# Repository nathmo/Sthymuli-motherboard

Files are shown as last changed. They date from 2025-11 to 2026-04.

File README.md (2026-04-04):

# Sthymuli-motherboard
This repo contains the PCB for the Sthymuli motherboard. Sthymuli is an educative robot aimed at children whith the aim of promoting collaborative learning.

The motherboard is designed arround a doughnut shape with addons that plug in the center. the shape was chosen to encourage equal access to up to four children at a time interracting with the device.

the circuit is splitted between one motherboard and three cardinalboard 
this repo has the motherboard


the cardinal board can be found there : https://github.com/nathmo/Sthymuli-cardinalboard


# Feature
The device contains the following sensors 

===

* # USB-C connector
* # Batterie + BMS
* # ESP32 + STM32
* # Speaker
* # Microphone
* # capacitive buttons (distributed arround the doughnut as discussed last time)
* # IR remote receive
* # 4 IR proximity Sensor
* # Motor Driver (so they can just connect the two wire of the motor and dont need to add a Hbridge on the dauther board
* # RGB LED (there I need to count how many and decide with you what we keep and what we breakout for the daugther board

# Daugther boards

the following will be available for the daugther board :

* IMU
* color sensor
* 2 DC motor channel
* LEDs
* IR proximity sensor / analog pin that can be used for sensing

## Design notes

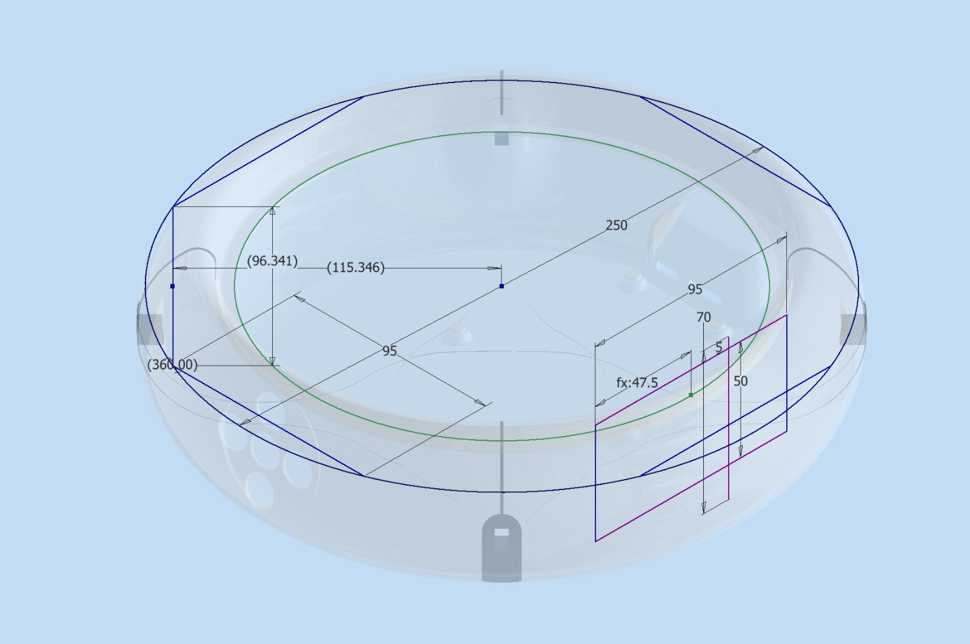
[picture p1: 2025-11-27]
enclosure_sktech_concept.jpg

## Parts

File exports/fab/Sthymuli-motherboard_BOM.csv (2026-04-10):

Comment | Designator | Footprint | JLCPCB Part #
CL05B104KO5NNNC | C1, C2, C3, C4, C5, C6, C7, C32, C45, C54, C58, C65, C67, C78, C86, C89, C94, C96 | C_0402_1005Metric | C1525
CL05B224KO5NNNC | C26, C27, C28, C29, C98 | C_0402_1005Metric | C16772
CL21B105KBFNNNE | C30, C34, C35, C69, C70, C79, C81, C83, C90, C91, C92, C93 | C_0805_2012Metric | C28323
0402CG101J500NT | C31, C33, C61, C62, C63, C66 | C_0402_1005Metric | C1546
CL21A106KAYNNNE | C36, C37, C38, C41, C49, C50, C51, C53, C56, C57, C84, C88, C95 | C_0805_2012Metric | C15850
0402B222K500NT | C39 | C_0402_1005Metric | C1531
CL05A474KP5NNNC | C40 | C_0402_1005Metric | C47339
0402CG330J500NT | C42 | C_0402_1005Metric | C1562
0402CG150J500NT | C43 | C_0402_1005Metric | C1548
0805B681K500NT | C44 | C_0805_2012Metric | C1754
0805B333K500NT | C46, C47 | C_0805_2012Metric | C1739
CL05B103KB5NNNC | C48, C72, C76 | C_0402_1005Metric | C15195
0402B473K500NT | C52, C55 | C_0402_1005Metric | C82219
CL21A226MAQNNNE | C59, C60, C68, C71 | C_0805_2012Metric | C45783
CL21A225KBQNNNE | C64 | C_0805_2012Metric | C377773
0805B152K500NT | C73 | C_0805_2012Metric | C1717
CL05C331JB5NNNC | C74 | C_0402_1005Metric | C13533
CL21A475KAQNNNE | C75 | C_0805_2012Metric | C1779
0402B102K500NT | C80, C82 | C_0402_1005Metric | C1523
0402CG200J500NT | C85, C87 | C_0402_1005Metric | C1554
CL21A226MAQNNNE | C97 | C_0805_2012Metric | C45783
WS2812B-V5/W | D1, D2, D3, D4, D5, D6, D7 | LED_WS2812B_PLCC4_5.0x5.0mm_P3.2mm | C2874885
SM4007PL | D30, D31, D34 | D_SOD-123F | C64898
LESD5D5.0CT1G | D32, D33 | D_SOD-523 | C5246195
ES8374 | ES1 | QFN-28-1EP_4x4mm_P0.45mm_EP2.4x2.4mm | C365738
AO3401A | Q10 | SOT-23 | C15127
HYCW498-USBC16-735B | J1 | USB_C_Receptacle_G-Switch_GT-USB-7010ASV | C42400252
FHD4020S-2R2MT | L1 | FHD4020S-2R2MT | C602029
FXL0630-3R3-M | L2, L3 | FXL0630-3R3-M | C167219
TDK VFS5045VA301 | L4 | TDK VFS5045VA301 | C6913904
KLJ-01304T-08R07W | LS1 | Speaker KELIKING KLJ-01304T-08R07W | C18186315
MIC-4013-G-G00 | MKTD4015BPN1 | SAMZO MIC-4013-G-G00 | C42371093
CSD17551Q3A | Q1, Q2, Q3, Q4, Q5, Q6 | VSON-8_3.3x3.3mm_P0.65mm_NexFET | C2876535
CSD25402Q3A | Q7 | VSON-8_3.3x3.3mm_P0.65mm_NexFET | C111356
NX7002AKVL | Q8, Q9 | SOT-23 | C551606
0603WAF100JT5E | R1, R2, R3, R4, R6, R9, R15, R36, R37 | C_0201_0603Metric | C22859
0603WAF5101T5E | R5, R7 | C_0201_0603Metric | C23186
0603WAF1000T5E | R8, R13, R16, R48, R59, R69, R70 | C_0201_0603Metric | C22775
FRM121WFR001TM | R14 | R_1206_3216Metric | C7467246
0603WAF1003T5E | R17 | C_0201_0603Metric | C25803
0603WAF3003T5E | R18 | C_0201_0603Metric | C23024
0603WAF1005T5E | R19, R26 | C_0201_0603Metric | C7250
0603WAF4703T5E | R20 | C_0201_0603Metric | C23178
0603WAF3003T5E | R21 | C_0201_0603Metric | C23024
0603WAF2201T5E | R22, R23, R49, R58 | C_0201_0603Metric | C4190
0603WAF5101T5E | R24, R28 | C_0201_0603Metric | C23186
0603WAF4022T5E | R25 | C_0201_0603Metric | C12447
0603WAF100KT5E | R27 | C_0201_0603Metric | C22936
0603WAF499KT5E | R29, R31 | C_0201_0603Metric | C23165
0603WAJ010LT5E | R30, R43 | C_0201_0603Metric | C620909
0603WAF1002T5E | R32, R33, R34, R42, R45, R46, R47, R71 | C_0201_0603Metric | C25804
0603WAF3002T5E | R35 | C_0201_0603Metric | C22984
0603WAF4702T5E | R38 | C_0201_0603Metric | C25819
0603WAF1502T5E | R39 | C_0201_0603Metric | C22809
0603WAF1373T5E | R40 | C_0201_0603Metric | C22872
0603WAF5362T5E | R41 | C_0201_0603Metric | C23074
0603WAF1001T5E | R44 | C_0201_0603Metric | C21190
0603WAF3301T5E | R50, R51 | C_0201_0603Metric | C22978
0603WAF270JT5E | R60, R61 | C_0201_0603Metric | C25190
XKB5858-W-F | SW1, SW2, SW3, SW4 | XKB5858 | C2884737
NCP18XH103F03RB | TH1 | R_0603_1608Metric | C13564
ESP32-S3-WROOM-1-N16 | U1 | ESP32-S3-WROOM-1 | C2913199
TPAP2112K-3.3TRG1 | U2 | SOT-23-5 | C3021085
BQ76905RGRR | U3 | IC_BQ76905RGRR | C22394458
AP62300WU-7 | U4, U6 | TSOT-23-6 | C1880390
BQ25713RSNR | U5 | QFN-32-1EP_4x4mm_P0.4mm_EP2.9x2.9mm | BQ25713RSNR
MCP23017-E/SO | U7 | SOIC-28W_7.5x17.9mm_P1.27mm | C47023
AP22913CN4 | U8 | WLCSP-4_0.89x0.89mm_Layout2x2_P0.5mm | C2150198
IRM-H638T/TR2 | U9 | Everlight_IRM-H6xxT | C91447
74HC4051D,653 | U10, U12 | SOIC-16_3.9x9.9mm_P1.27mm | C9386
MCP6L01T-E/OT | U11 | SOT-23-5 | C145745
LSM6DS3TR-C | U14 | LGA-14_3x2.5mm_P0.5mm_LayoutBorder3x4y | C967633
ITR9909 | U15 | ITR_9909_Horizontal | C53399
ITR9909 | U16 | ITR_9909_Vertical | C53399
Battery_Cell | BT4 | Battery_Holder_18650_robop | C7525438
Conn_02x08_Counter_Clockwise | J8, J11, J12 | PinSocket_2x08_P2.54mm_Vertical_SMD | C41427537

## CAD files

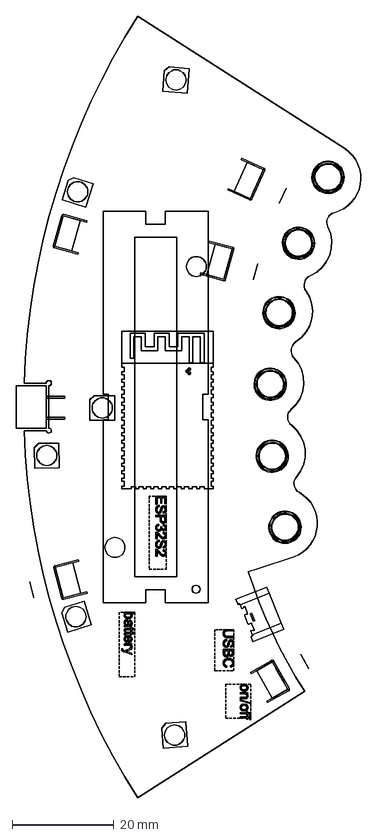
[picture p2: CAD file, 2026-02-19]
DXF_B_MainPCB.dxf
68.1 x 153.6 mm

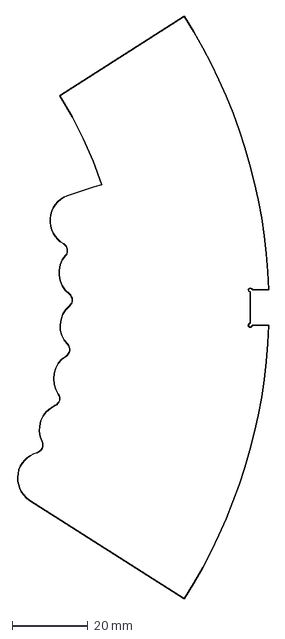
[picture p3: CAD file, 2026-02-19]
DXF_A_MainPCB.dxf
66.6 x 153.6 mm

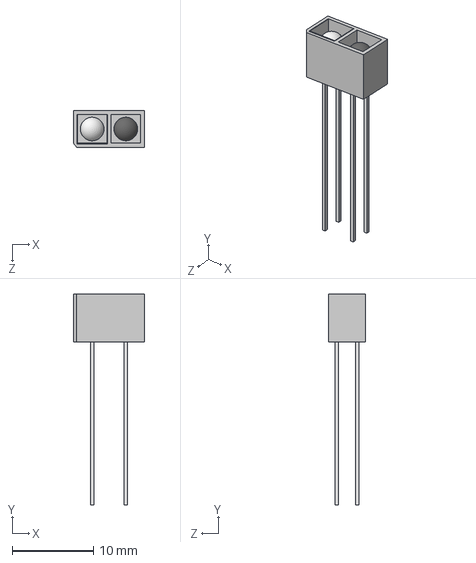
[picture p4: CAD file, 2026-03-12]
footprint/ITR-9909.stp
8.70 x 25.9 x 4.50 mm

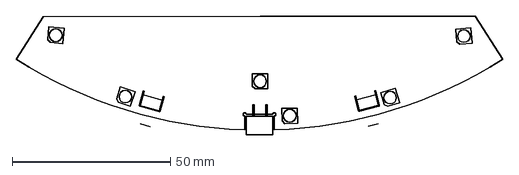
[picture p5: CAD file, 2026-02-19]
DXF_B_MinionPCB.dxf
153.6 x 37.4 mm

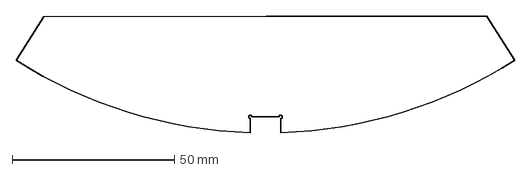
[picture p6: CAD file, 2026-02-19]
DXF_A_MinionPCB.dxf
153.6 x 35.9 mm

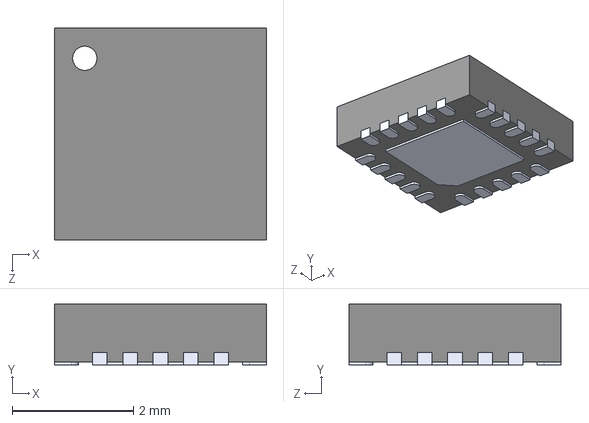
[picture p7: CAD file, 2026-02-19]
footprint/BQ76905RGRR.step
3.50 x 1.00 x 3.50 mm

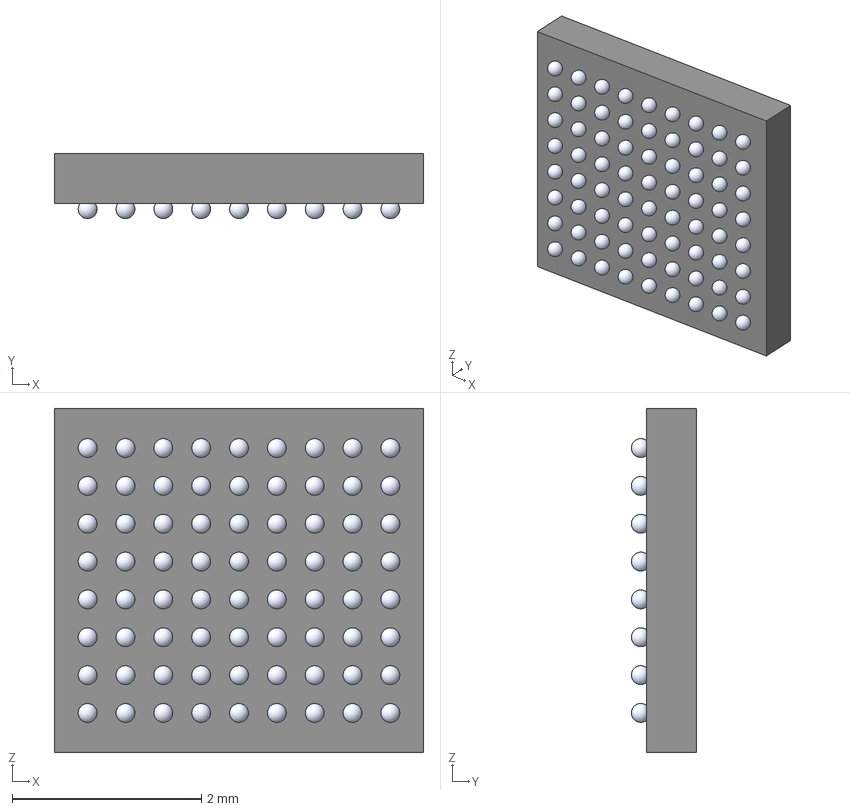
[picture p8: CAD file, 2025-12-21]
footprint/MAX77818EWZ_T.step
3.90 x 0.69 x 3.64 mm
Body_Solid1
Body002_Solid1
BALL_0001
BALL_0002
BALL_0003
BALL_0004
BALL_0005
BALL_0006
BALL_0007
BALL_0008
BALL_0009
BALL_0010
BALL_0011
BALL_0012
BALL_0013
BALL_0014
BALL_0015
BALL_0016
BALL_0017
BALL_0018
BALL_0019
BALL_0020
BALL_0021
BALL_0022
BALL_0023
BALL_0024
BALL_0025
BALL_0026
BALL_0027
BALL_0028
BALL_0029
BALL_0030
BALL_0031
BALL_0032
BALL_0033
BALL_0034
BALL_0035
BALL_0036
BALL_0037
BALL_0038
BALL_0039
BALL_0040
BALL_0041
BALL_0042
BALL_0043
BALL_0044
BALL_0045
BALL_0046
BALL_0047
BALL_0048
BALL_0049
BALL_0050
BALL_0051
BALL_0052
BALL_0053
BALL_0054
BALL_0055
BALL_0056
BALL_0057
BALL_0058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

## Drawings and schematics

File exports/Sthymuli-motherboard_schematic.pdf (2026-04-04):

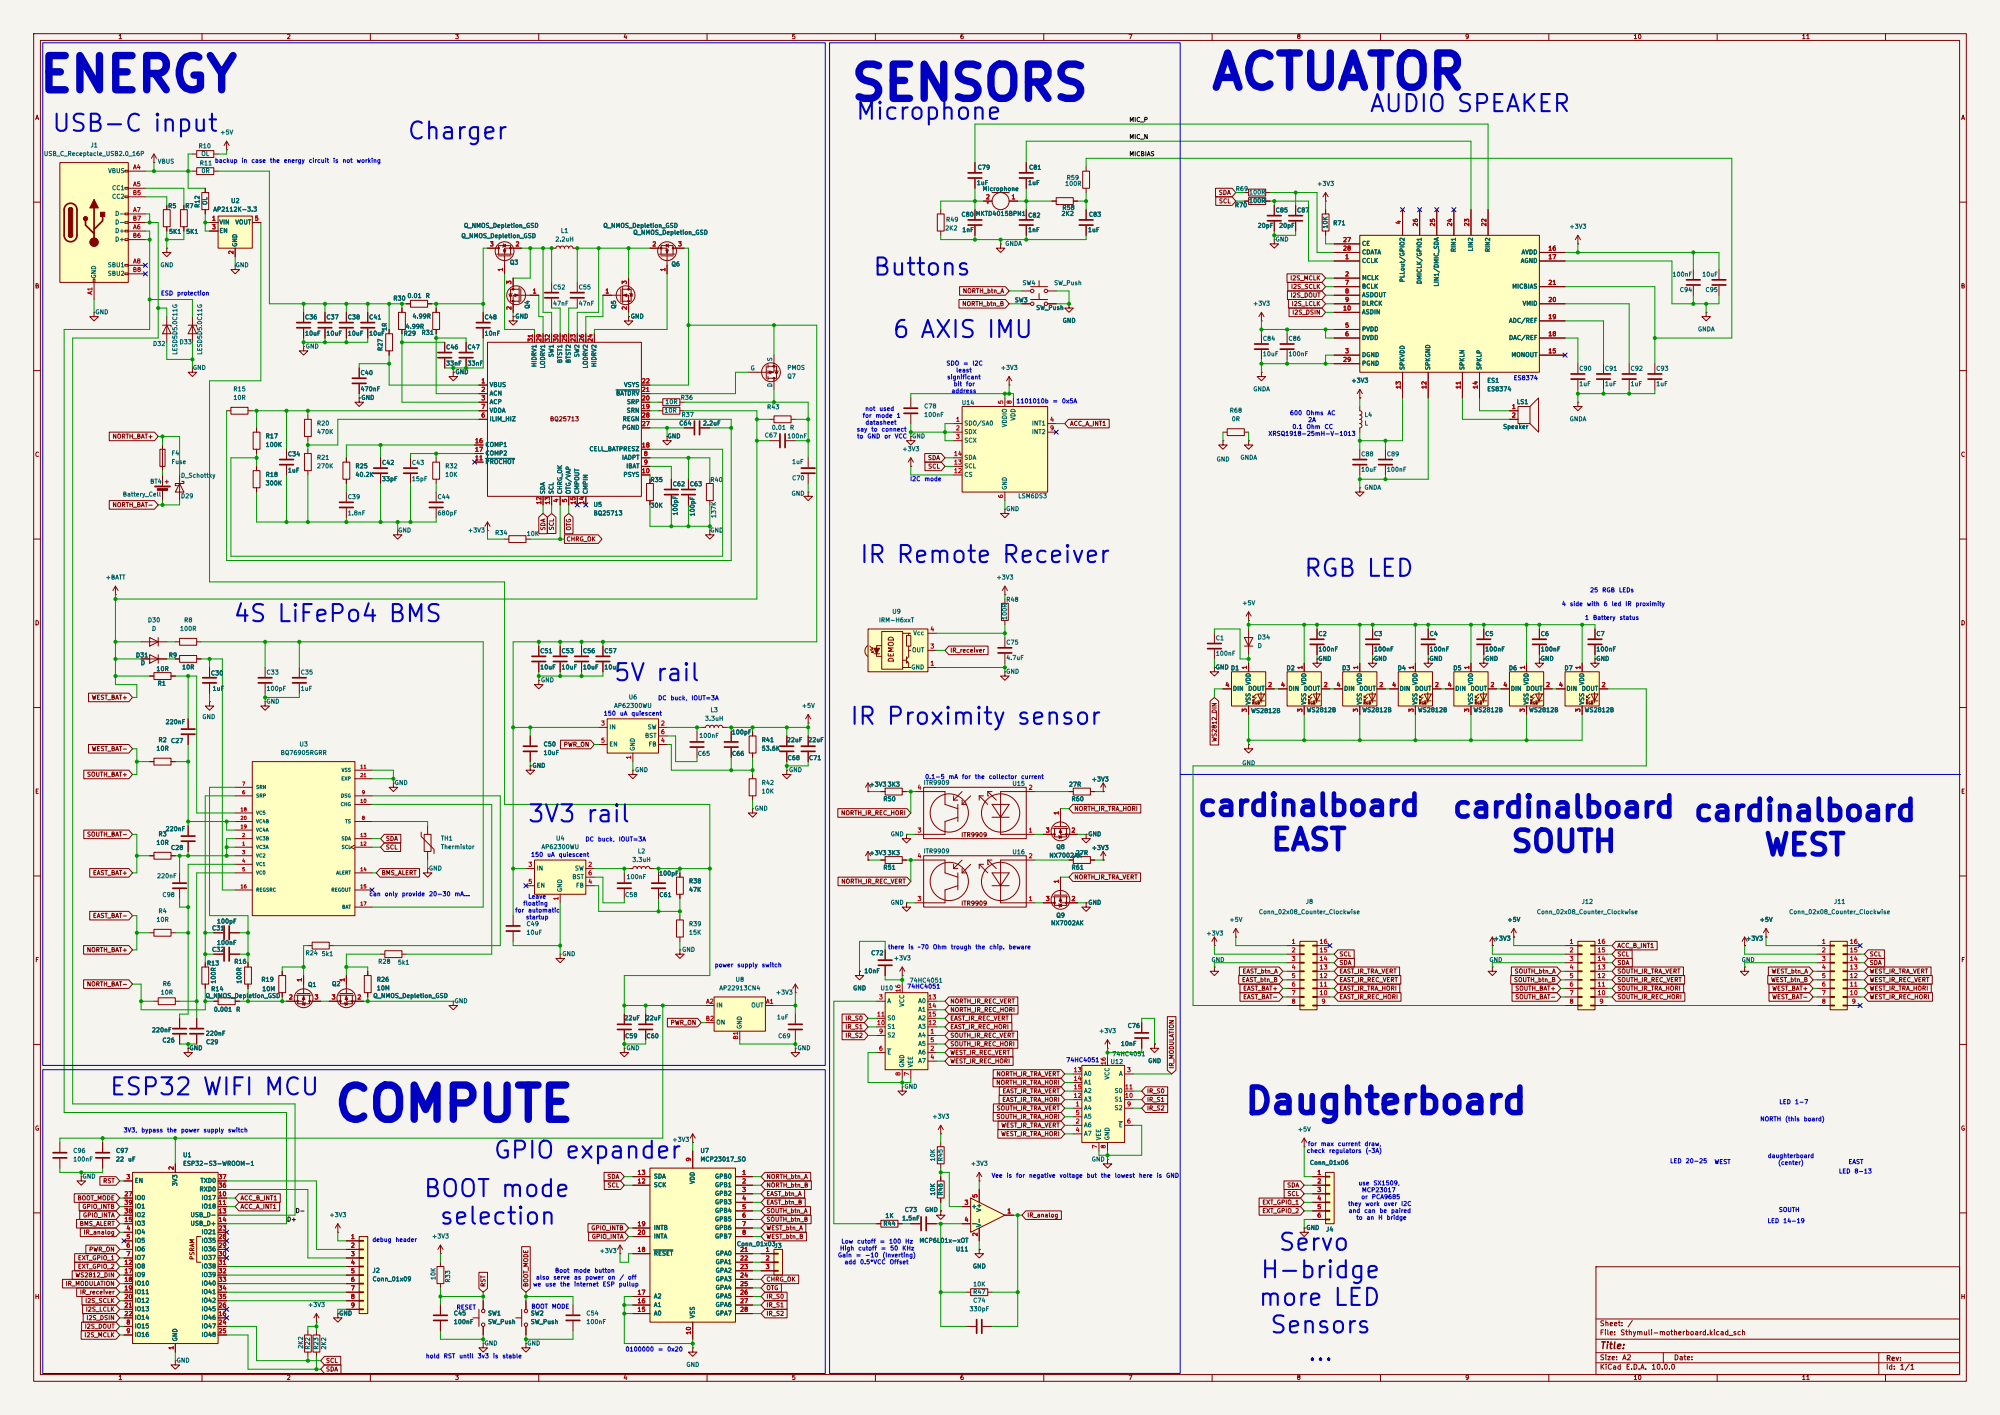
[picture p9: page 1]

backup in case the energy circuit is not working

not used
for mode 1
datasheet say to connect

to GND or VCC

25 RGB LEDs 4 side with 6 led IR proximity

0.1-5 mA for the collector current 5V rail

can only provide 20-30 mA...

for max current draw, check regulators (~3A)

they work over I2C
and can be paired
to an H bridge

Low cutoff = 100 Hz High cutoff = 50 KHz Gain = -10 (Inverting)

also serve as power on / off we use the internet ESP pullup

hold RST until 3v3 is stable

Size: A2 | Rev:
KiCad E.D.A. 10.0.0 | Id: 1/1

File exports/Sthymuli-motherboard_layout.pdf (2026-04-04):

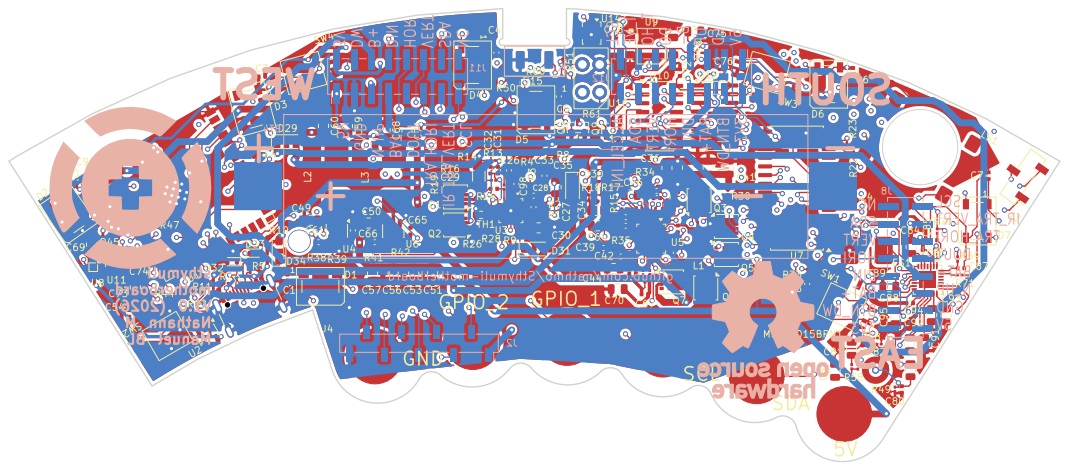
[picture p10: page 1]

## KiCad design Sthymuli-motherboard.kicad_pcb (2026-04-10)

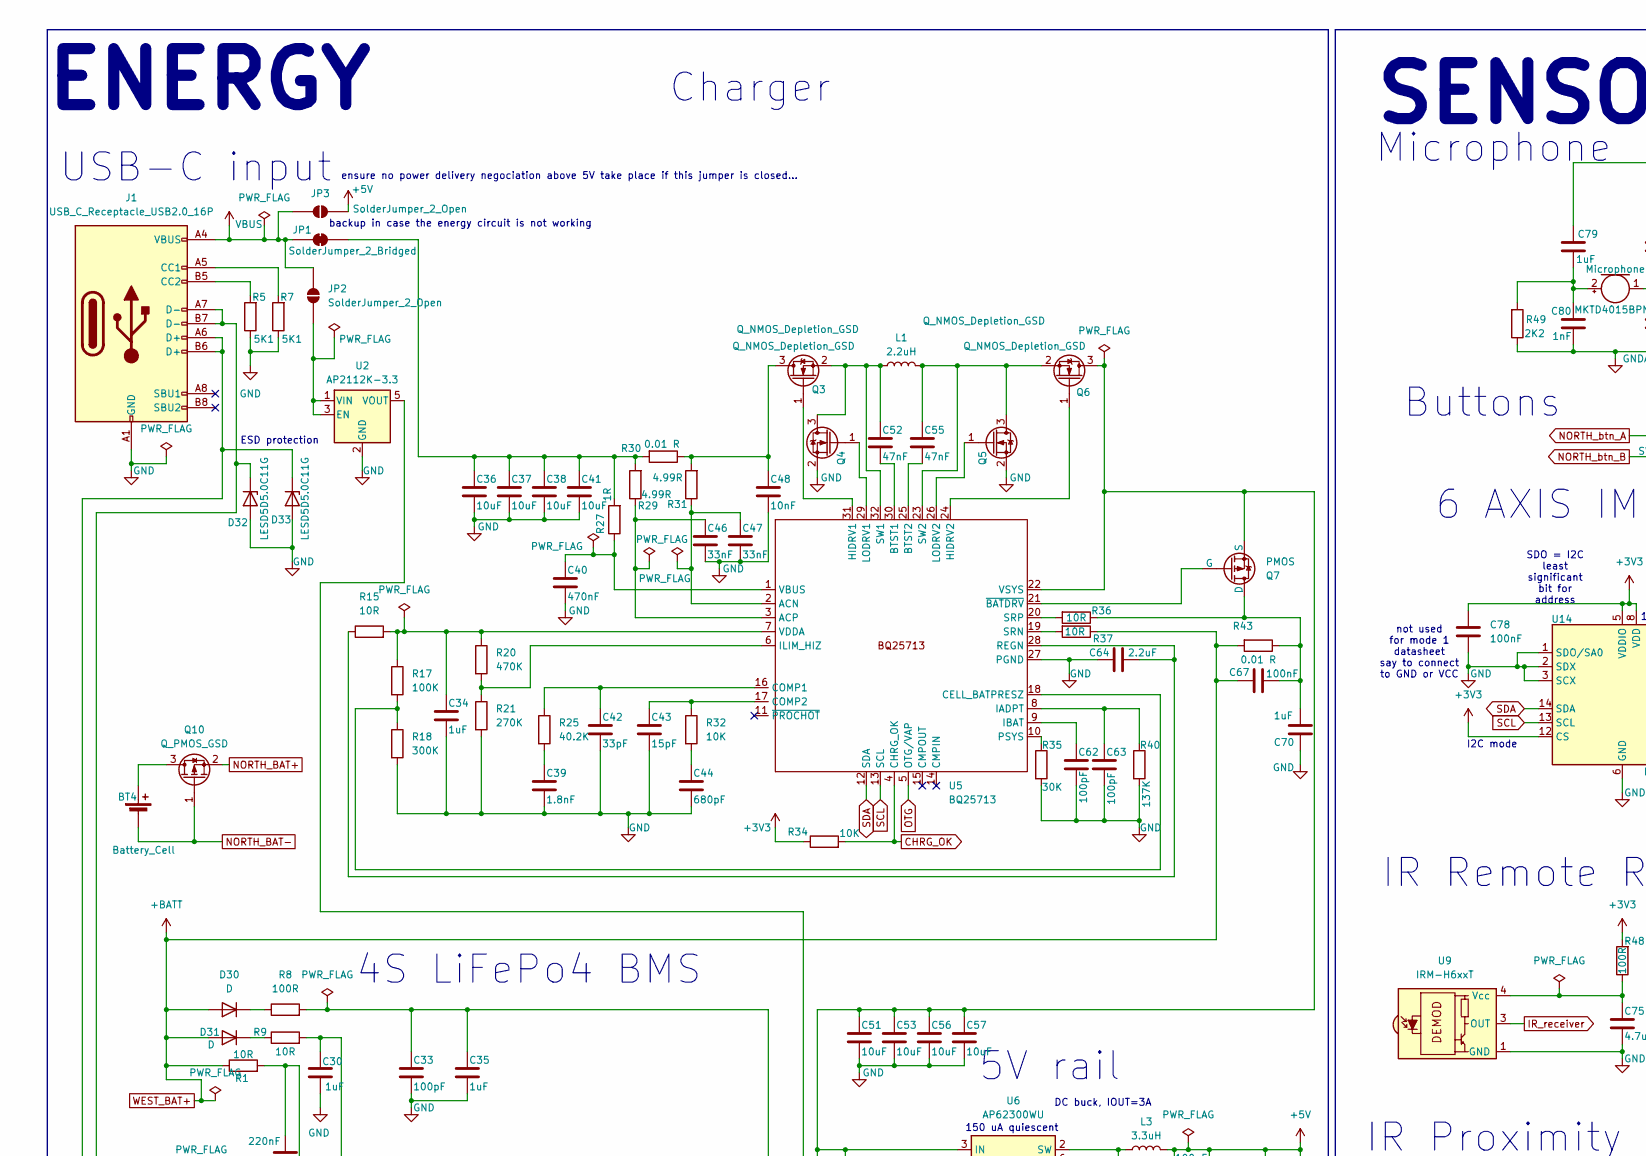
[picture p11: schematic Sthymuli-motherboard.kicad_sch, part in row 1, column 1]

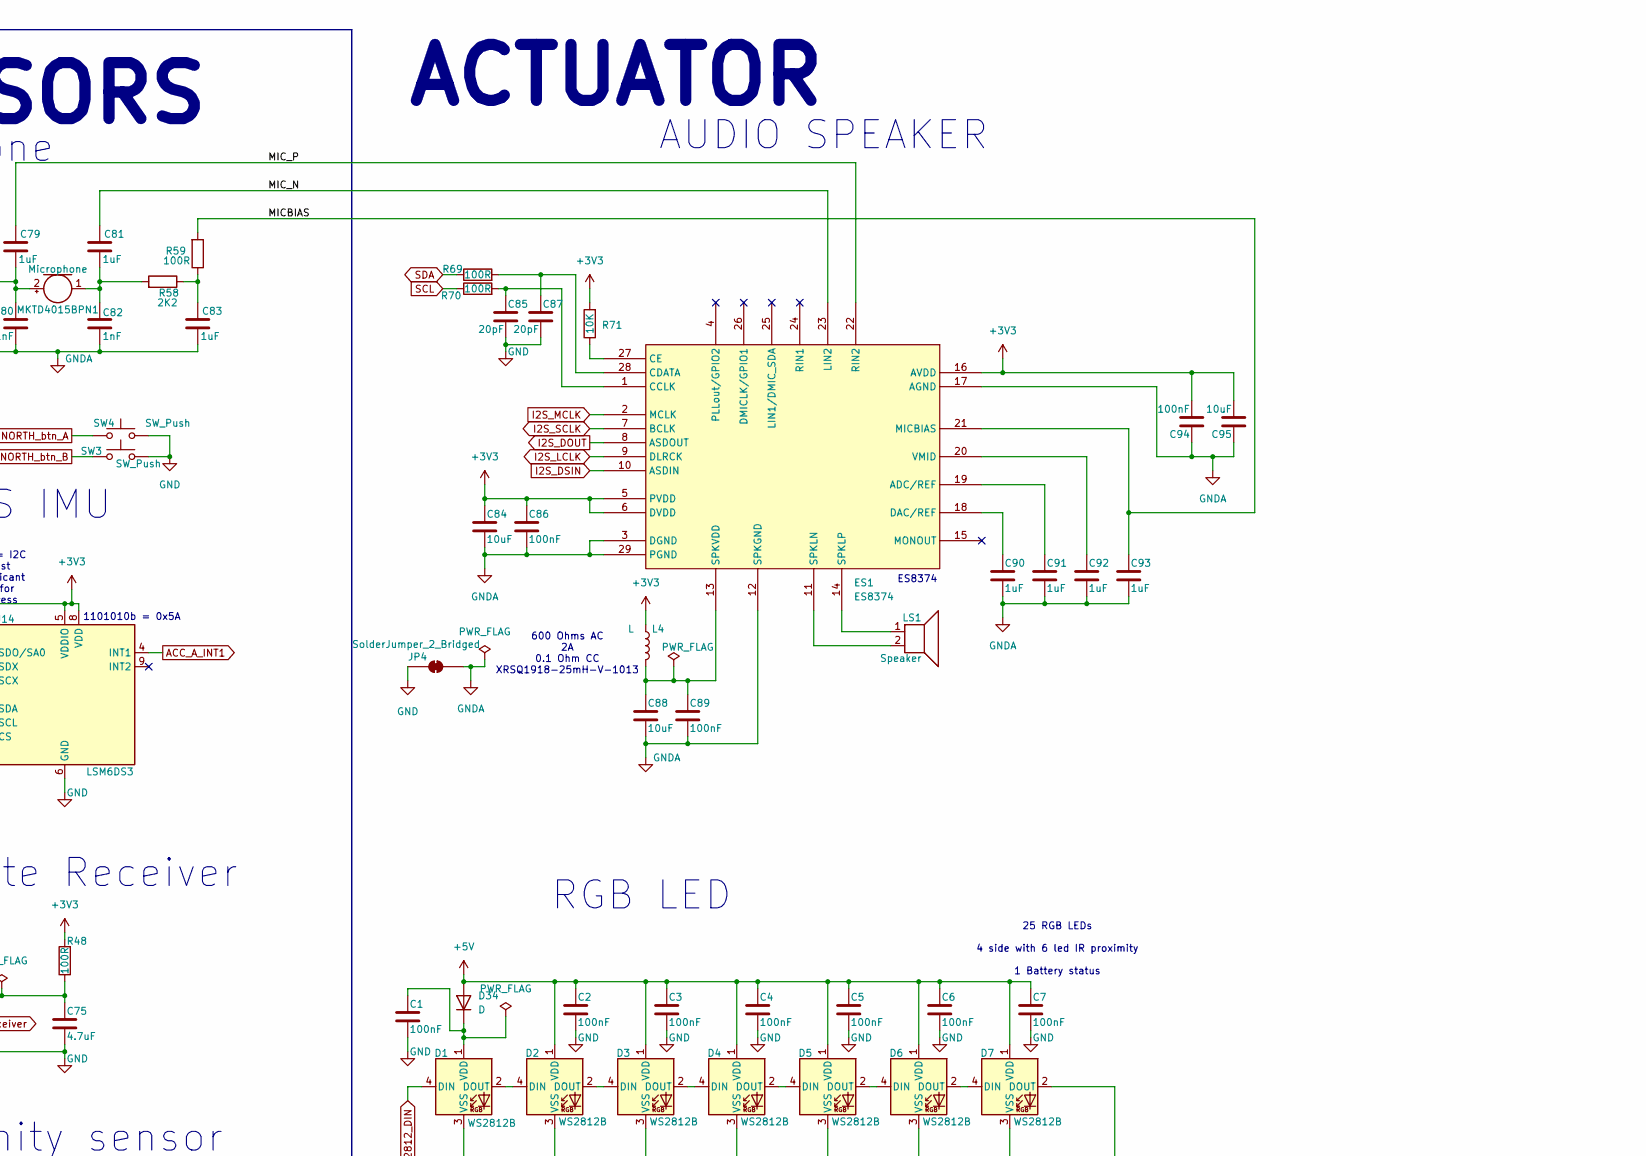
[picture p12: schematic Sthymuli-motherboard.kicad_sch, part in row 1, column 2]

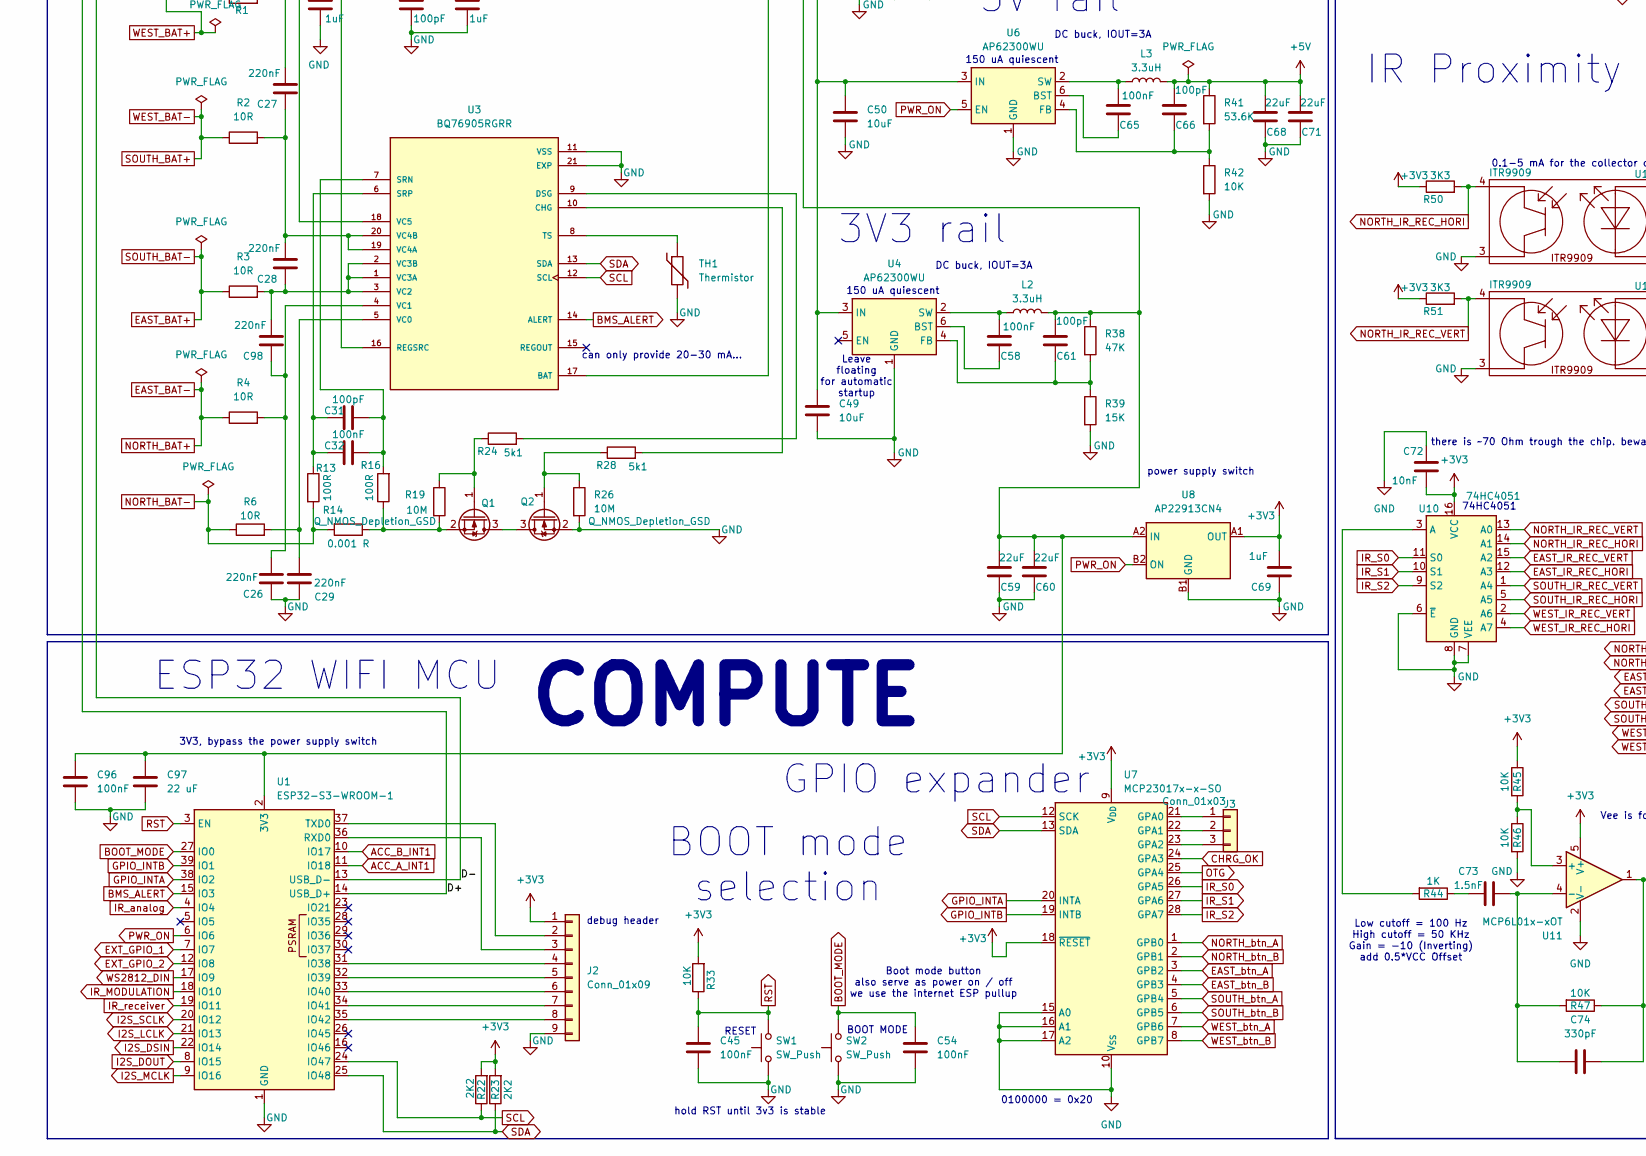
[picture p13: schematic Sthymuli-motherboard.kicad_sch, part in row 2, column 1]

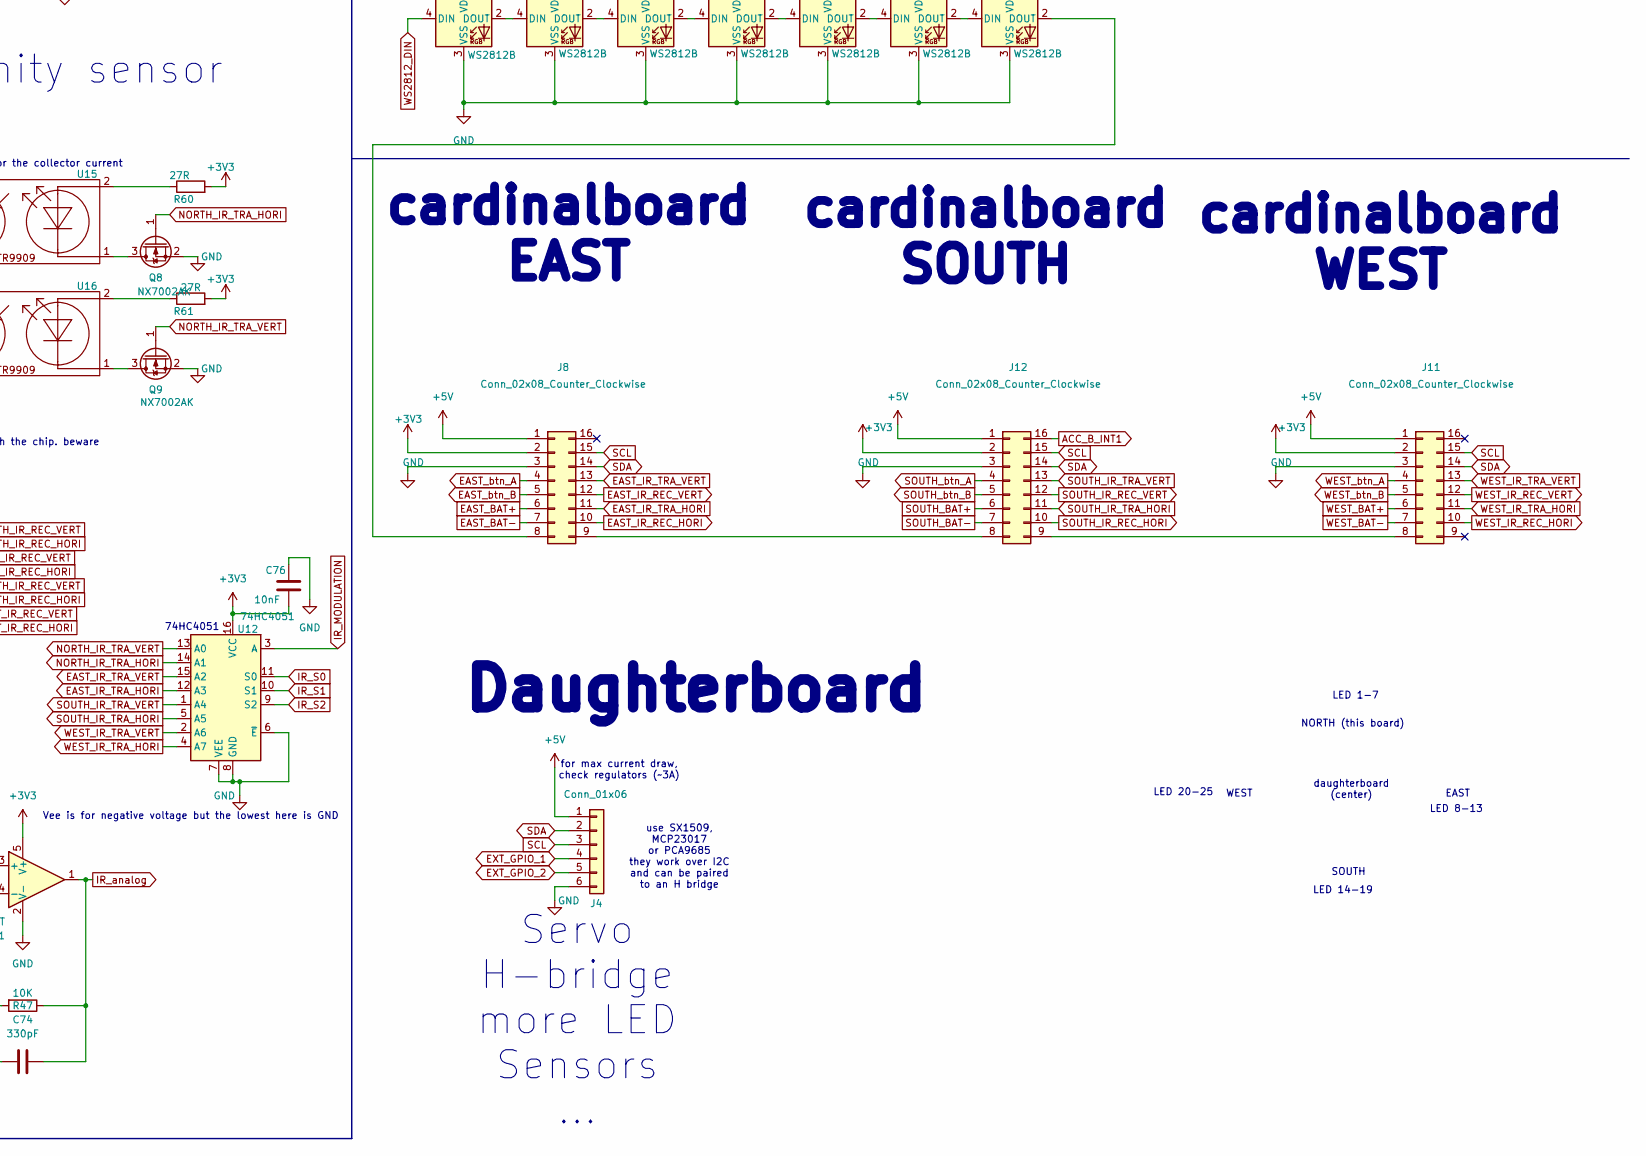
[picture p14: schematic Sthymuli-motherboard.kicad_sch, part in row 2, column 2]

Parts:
BT4: Battery_Cell; Battery_Holder_18650_robop
C1, C2, C3, C4, C5, C6, C7, C32, C45, C54, C58, C65, C67, C78, C86, C89, C94, C96: 100nF; C_0402_1005Metric
C26, C27, C28, C29, C98: 220nF; C_0402_1005Metric
C30, C34, C35, C69, C70, C79, C81, C83, C90, C91, C92, C93: 1uF; C_0805_2012Metric
C31, C33, C61, C62, C63, C66: 100pF; C_0402_1005Metric
C36, C37, C38, C41, C49, C50, C51, C53, C56, C57, C84, C88, C95: 10uF; C_0805_2012Metric
C39: 1.8nF; C_0402_1005Metric
C40: 470nF; C_0402_1005Metric
C42: 33pF; C_0402_1005Metric
C43: 15pF; C_0402_1005Metric
C44: 680pF; C_0805_2012Metric
C46, C47: 33nF; C_0805_2012Metric
C48, C72, C76: 10nF; C_0402_1005Metric
C52, C55: 47nF; C_0402_1005Metric
C59, C60, C68, C71: 22uF; C_0805_2012Metric
C64: 2.2uF; C_0805_2012Metric
C73: 1.5nF; C_0805_2012Metric
C74: 330pF; C_0402_1005Metric
C75: 4.7uF; C_0805_2012Metric
C80, C82: 1nF; C_0402_1005Metric
C85, C87: 20pF; C_0402_1005Metric
C97: 22 uF; C_0805_2012Metric
D1, D2, D3, D4, D5, D6, D7: WS2812B; LED_WS2812B_PLCC4_5.0x5.0mm_P3.2mm
D30, D31, D34: D; D_SOD-123F
D32, D33: LESD5D5.0C11G; D_SOD-523
ES1: ES8374; QFN-28-1EP_4x4mm_P0.45mm_EP2.4x2.4mm
J1: USB_C_Receptacle_USB2.0_16P; USB_C_Receptacle_G-Switch_GT-USB-7010ASV
J2: Conn_01x09; PinSocket_1x09_P2.54mm_Vertical_SMD_Pin1Left
J3: Conn_01x03; PinSocket_1x03_P2.54mm_Vertical_SMD_Pin1Left
J4: Conn_01x06; ConnectorSpring
J8, J11, J12: Conn_02x08_Counter_Clockwise; PinSocket_2x08_P2.54mm_Vertical_SMD
JP1, JP4: SolderJumper_2_Bridged; SolderJumper-2_P1.3mm_Bridged_RoundedPad1.0x1.5mm
JP2, JP3: SolderJumper_2_Open; SolderJumper-2_P1.3mm_Open_RoundedPad1.0x1.5mm
L1: 2.2uH; FHD4020S-2R2MT
L2, L3: 3.3uH; FXL0630-3R3-M
L4: L; TDK VFS5045VA301
LS1: Speaker; Speaker KELIKING KLJ-01304T-08R07W
MKTD4015BPN1: Microphone; SAMZO MIC-4013-G-G00
Q1, Q2, Q3, Q4, Q5, Q6: Q_NMOS_Depletion_GSD; VSON-8_3.3x3.3mm_P0.65mm_NexFET
Q7: PMOS; VSON-8_3.3x3.3mm_P0.65mm_NexFET
Q8, Q9: NX7002AK; SOT-23
Q10: Q_PMOS_GSD; TSOT-23
R1, R2, R3, R4, R6, R9, R15, R36, R37: 10R; R_0603_1608Metric
R5, R7: 5K1; R_0603_1608Metric
R8, R13, R16, R48, R59, R69, R70: 100R; R_0603_1608Metric
R14: 0.001 R; R_1206_3216Metric
R17: 100K; R_0603_1608Metric
R18: 300K; R_0603_1608Metric
R19, R26: 10M; R_0603_1608Metric
R20: 470K; R_0603_1608Metric
R21: 270K; R_0603_1608Metric
R22, R23, R49, R58: 2K2; R_0603_1608Metric
R24, R28: 5k1; R_0603_1608Metric
R25: 40.2K; R_0603_1608Metric
R27: 1R; R_0603_1608Metric
R29, R31: 4.99R; R_0603_1608Metric
R30, R43: 0.01 R; R_0603_1608Metric
R32, R33, R34, R42, R45, R46, R47, R71: 10K; R_0603_1608Metric
R35: 30K; R_0603_1608Metric
R38: 47K; R_0603_1608Metric
R39: 15K; R_0603_1608Metric
R40: 137K; R_0603_1608Metric
R41: 53.6K; R_0603_1608Metric
R44: 1K; R_0603_1608Metric
R50, R51: 3K3; R_0603_1608Metric
R60, R61: 27R; R_0603_1608Metric
SW1, SW2, SW3, SW4: SW_Push; XKB5858
TH1: Thermistor; R_0603_1608Metric
U1: ESP32-S3-WROOM-1
U2: AP2112K-3.3; SOT-23-5
U3: BQ76905RGRR; IC_BQ76905RGRR; PARTREV November 2023
U4, U6: AP62300WU; TSOT-23-6
U5: BQ25713; QFN-32-1EP_4x4mm_P0.4mm_EP2.9x2.9mm
U7: MCP23017x-x-SO; SOIC-28W_7.5x17.9mm_P1.27mm
U8: AP22913CN4; WLCSP-4_0.89x0.89mm_Layout2x2_P0.5mm
U9: IRM-H6xxT; Everlight_IRM-H6xxT
U10, U12: 74HC4051; SOIC-16_3.9x9.9mm_P1.27mm
U11: MCP6L01x-xOT; SOT-23-5
U14: LSM6DS3; LGA-14_3x2.5mm_P0.5mm_LayoutBorder3x4y
U15: ITR9909; ITR_9909_Horizontal
U16: ITR9909; ITR_9909_Vertical

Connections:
+3V3: C69.2, C72.2, C76.2, C78.1, C84.1, C86.1, C94.2, C95.2, ES1.5 (PVDD), ES1.6 (DVDD), ES1.16 (AVDD), J2.1, J8.2, J11.2, J12.2, L4.1, R22.2, R23.2, R33.2, R34.1, R45.1, R48.2, R50.1, R51.1, R60.2, R61.2, R71.2, U7.9 (V_{DD}), U7.18 (~RESET), U8.A1 (OUT), U10.16 (VCC), U11.5 (V+), U12.16 (VCC), U14.5 (VDDIO), U14.8 (VDD), U14.12 (CS)
+5V: C2.1, C3.1, C4.1, C5.1, C6.1, C7.1, C66.2, C68.2, C71.2, D2.1 (VDD), D3.1 (VDD), D4.1 (VDD), D5.1 (VDD), D6.1 (VDD), D7.1 (VDD), D34.2 (A), J4.1, J8.1, J11.1, J12.1, JP3.1 (A), L3.2, R41.1
/D+: D33.1 (K), J1.A6 (D+), J1.B6 (D+), U1.14 (USB_D+)
/D-: D32.1 (K), J1.A7 (D-), J1.B7 (D-), U1.13 (USB_D-)
/MICBIAS: C93.1, ES1.21 (MICBIAS), R59.2
/MIC_N: C81.1, ES1.23 (LIN2)
/MIC_P: C79.1, ES1.22 (RIN2)
ACC_A_INT1: U1.11 (IO18), U14.4 (INT1)
ACC_B_INT1: J12.16, U1.10 (IO17)
BMS_ALERT: U1.15 (IO3), U3.14 (ALERT)
BOOT_MODE: C54.1, SW2.2, U1.27 (IO0)
CHRG_OK: R34.2, U5.4 (CHRG_OK), U7.24 (GPA3)
EAST_BAT+: J8.6, J12.7, R3.1
EAST_BAT-: J8.7, Q10.2 (S), R4.1
EAST_IR_REC_HORI: J8.10, U10.12 (A3)
EAST_IR_REC_VERT: J8.12, U10.15 (A2)
EAST_IR_TRA_HORI: J8.11, U12.12 (A3)
EAST_IR_TRA_VERT: J8.13, U12.15 (A2)
EAST_btn_A: J8.4, U7.3 (GPB2)
EAST_btn_B: J8.5, U7.4 (GPB3)
EXT_GPIO_1: J4.4, U1.7 (IO7)
EXT_GPIO_2: J4.5, U1.12 (IO8)
GND: C1.2, C2.2, C3.2, C4.2, C5.2, C6.2, C7.2, C26.1, C29.1, C30.2, C33.2, C34.2, C35.2, C36.2, C37.2, C38.2, C39.2, C40.2, C41.2, C42.2, C43.2, C44.2, C45.2, C46.2, C47.2, C48.2, C49.2, C50.2, C51.2, C53.2, C54.2, C56.2, C57.2, C59.1, C60.1, C62.2, C63.2, C64.1, C68.1, C69.1, C70.1, C71.1, C72.1, C75.2, C76.1, C78.2, C85.2, C87.2, C96.2, C97.2, D1.3 (VSS), D2.3 (VSS), D3.3 (VSS), D4.3 (VSS), D5.3 (VSS), D6.3 (VSS), D7.3 (VSS), D32.2 (A), D33.2 (A), J1.A1 (GND), J1.A12 (GND), J1.B1 (GND), J1.B12 (GND), J2.9, J4.6, J8.3, J11.3, J12.3, JP4.1 (A), Q2.2 (S), Q4.2 (S), Q5.2 (S), Q8.2 (S), Q9.2 (S), R5.1, R7.1, R18.2, R21.2, R26.2, R35.2, R39.2, R40.2, R42.2, R46.2, SW1.1, SW2.1, SW3.2, SW4.2, TH1.2, U1.1 (GND), U1.40 (GND), U1.41 (GND), U2.2 (GND), U3.11 (VSS), U3.21 (EXP), U4.1 (GND), U5.27 (PGND), U6.1 (GND), U7.10 (V_{SS}), U7.15 (A0), U7.16 (A1), U7.17 (A2), U8.B1 (GND), U9.1 (GND), U9.2 (GND), U10.6 (~E), U10.7 (VEE), U10.8 (GND), U11.2 (V-), U12.6 (~E), U12.7 (VEE), U12.8 (GND), U14.1 (SDO/SA0), U14.2 (SDX), U14.3 (SCX), U14.6 (GND), U14.7 (GND), U15.3, U16.3
GNDA: C80.2, C82.2, C83.2, C84.2, C86.2, C88.2, C89.2, C90.2, C91.2, C92.2, C93.2, C94.1, C95.1, ES1.3 (DGND), ES1.12 (SPKGND), ES1.17 (AGND), ES1.29 (PGND), JP4.2 (B), R49.1
GPIO_INTA: U1.38 (IO2), U7.20 (INTA)
GPIO_INTB: U1.39 (IO1), U7.19 (INTB)
I2S_DOUT: ES1.8 (ASDOUT), U1.8 (IO15)
I2S_DSIN: ES1.10 (ASDIN), U1.22 (IO14)
I2S_LCLK: ES1.9 (DLRCK), U1.21 (IO13)
I2S_MCLK: ES1.2 (MCLK), U1.9 (IO16)
I2S_SCLK: ES1.7 (BCLK), U1.20 (IO12)
IR_MODULATION: U1.18 (IO10), U12.3 (A)
IR_S0: U7.26 (GPA5), U10.11 (S0), U12.11 (S0)
IR_S1: U7.27 (GPA6), U10.10 (S1), U12.10 (S1)
IR_S2: U7.28 (GPA7), U10.9 (S2), U12.9 (S2)
IR_analog: C74.1, R47.1, U1.4 (IO4), U11.1
IR_receiver: U1.19 (IO11), U9.3 (OUT)
NORTH_BAT-: BT4.2 (-), Q10.1 (G), R6.1, R13.2, R14.2
NORTH_IR_REC_HORI: R50.2, U10.14 (A1), U15.4
NORTH_IR_REC_VERT: R51.2, U10.13 (A0), U16.4
NORTH_IR_TRA_HORI: Q8.1 (G), U12.14 (A1)
NORTH_IR_TRA_VERT: Q9.1 (G), U12.13 (A0)
NORTH_btn_A: SW4.1, U7.1 (GPB0)
NORTH_btn_B: SW3.1, U7.2 (GPB1)
unnamed: BT4.1 (+), Q10.3 (D)
unnamed: C39.1, R25.2
unnamed: C44.1, R32.2
unnamed: C73.2, R44.1
unnamed: C83.1, R58.1, R59.1
unnamed: D1.2 (DOUT), D2.4 (DIN)
unnamed: C1.1, D1.1 (VDD), D34.1 (K)
unnamed: D2.2 (DOUT), D3.4 (DIN)
unnamed: D3.2 (DOUT), D4.4 (DIN)
unnamed: D4.2 (DOUT), D5.4 (DIN)
unnamed: D5.2 (DOUT), D6.4 (DIN)
unnamed: D6.2 (DOUT), D7.4 (DIN)
unnamed: D7.2 (DOUT), J8.8
unnamed: D30.1 (K), R8.1
unnamed: D31.1 (K), R9.1
unnamed: C91.1, ES1.19 (ADC/REF)
unnamed: C85.1, ES1.1 (CCLK), R70.2
unnamed: C87.1, ES1.28 (CDATA), R69.2
unnamed: ES1.27 (CE), R71.1
unnamed: C90.1, ES1.18 (DAC/REF)
unnamed: ES1.11 (SPKLN), LS1.2
unnamed: ES1.14 (SPKLP), LS1.1
unnamed: C88.1, C89.1, ES1.13 (SPKVDD), L4.2
unnamed: C92.1, ES1.20 (VMID)
unnamed: J1.A5 (CC1), R7.2
unnamed: J1.B5 (CC2), R5.2
unnamed: J2.2, U1.37 (TXD0)
unnamed: J2.3, U1.36 (RXD0)
unnamed: J2.4, U1.31 (IO38)
unnamed: J2.5, U1.32 (IO39)
unnamed: J2.6, U1.33 (IO40)
unnamed: J2.7, U1.34 (IO41)
unnamed: J2.8, U1.35 (IO42)
unnamed: J3.1, U7.21 (GPA0)
unnamed: J3.2, U7.22 (GPA1)
unnamed: J3.3, U7.23 (GPA2)
unnamed: J11.8, J12.9
unnamed: J8.9, J12.8
unnamed: C36.1, C37.1, C38.1, C41.1, JP1.2 (B), R27.2, R29.2, R30.2
unnamed: JP2.1 (A), U2.1 (VIN), U2.3 (EN)
unnamed: C79.2, C80.1, MKTD4015BPN1.2 (+), R49.2
unnamed: C81.2, C82.1, MKTD4015BPN1.1 (-), R58.2
unnamed: Q1.3 (D), Q2.3 (D)
unnamed: Q1.1 (G), R19.1, R24.1
unnamed: Q1.2 (S), R14.1, R16.1, R19.2
unnamed: Q2.1 (G), R26.1, R28.1
unnamed: C48.1, Q3.3 (D), R30.1, R31.2
unnamed: Q3.1 (G), U5.31 (HIDRV1)
unnamed: C52.1, L1.1, Q3.2 (S), Q4.3 (D), U5.32 (SW1)
unnamed: Q4.1 (G), U5.29 (LODRV1)
unnamed: C55.1, L1.2, Q5.3 (D), Q6.2 (S), U5.23 (SW2)
unnamed: Q5.1 (G), U5.26 (LODRV2)
unnamed: C49.1, C50.1, C51.1, C53.1, C56.1, C57.1, Q6.3 (D), Q7.3 (S), U4.3 (IN), U5.22 (VSYS), U6.3 (IN)
unnamed: Q6.1 (G), U5.24 (HIDRV2)
unnamed: C67.2, C70.2, Q7.1 (D), R36.1, R43.1
unnamed: Q7.2 (G), U5.21 (~BATDRV)
unnamed: Q8.3 (D), U15.1
unnamed: Q9.3 (D), U16.1
unnamed: R60.1, U15.2
unnamed: R61.1, U16.2
unnamed: C59.2, C60.2, C61.2, C96.1, C97.1, L2.2, R38.1, U1.2 (3V3), U2.5 (VOUT), U8.A2 (IN)
unnamed: C33.1, C35.1, R8.2, U3.17 (BAT)
unnamed: R28.2, U3.10 (CHG)
unnamed: R24.2, U3.9 (DSG)
unnamed: C30.1, R9.2, U3.16 (REGSRC)
unnamed: C31.2, C32.2, R16.2, U3.7 (SRN)
unnamed: C31.1, C32.1, R13.1, U3.6 (SRP)
unnamed: TH1.1, U3.8 (TS)
unnamed: C29.2, R6.2, U3.5 (VC0)
unnamed: C26.2, C98.1, R4.2, U3.4 (VC1)
unnamed: C28.1, C98.2, R3.2, U3.1 (VC3A), U3.2 (VC3B), U3.3 (VC2)
unnamed: C27.1, C28.2, R2.2, U3.19 (VC4A), U3.20 (VC4B)
unnamed: C27.2, R1.2, U3.18 (VC5)
unnamed: C58.1, U4.6 (BST)
unnamed: C61.1, R38.2, R39.1, U4.4 (FB)
unnamed: C58.2, L2.1, U4.2 (SW)
unnamed: C47.1, R31.1, U5.2 (ACN)
unnamed: C46.1, R29.1, U5.3 (ACP)
unnamed: C52.2, U5.30 (BTST1)
unnamed: C55.2, U5.25 (BTST2)
unnamed: R17.2, R18.1, U5.18 (CELL_BATPRESZ)
unnamed: C42.1, R25.1, U5.16 (COMP1)
unnamed: C43.1, R32.1, U5.17 (COMP2)
unnamed: C63.1, R40.1, U5.8 (IADPT)
unnamed: C62.1, U5.9 (IBAT)
unnamed: R20.2, R21.1, U5.6 (ILIM_HIZ)
unnamed: R35.1, U5.10 (PSYS)
unnamed: C64.2, R15.1, U5.28 (REGN)
unnamed: R37.2, U5.19 (SRN)
unnamed: R36.2, U5.20 (SRP)
unnamed: C40.1, R27.1, U5.1 (VBUS)
unnamed: C34.1, R15.2, R17.1, R20.1, U5.7 (VDDA)
unnamed: C65.1, U6.6 (BST)
unnamed: C66.1, R41.2, R42.1, U6.4 (FB)
unnamed: C65.2, L3.1, U6.2 (SW)
unnamed: C75.1, R48.1, U9.4 (Vcc)
unnamed: R44.2, U10.3 (A)
unnamed: R45.2, R46.1, U11.3 (+)
unnamed: C73.1, C74.2, R47.2, U11.4 (-)
OTG: U5.5 (OTG/VAP), U7.25 (GPA4)
PWR_ON: U1.6 (IO6), U6.5 (EN), U8.B2 (ON)
RST: C45.1, R33.1, SW1.2, U1.3 (EN)
SCL: J4.3, J8.15, J11.15, J12.15, R22.1, R70.1, U1.24 (IO47), U3.12 (SCL), U5.13 (SCL), U7.12 (SCK), U14.13 (SCL)
SDA: J4.2, J8.14, J11.14, J12.14, R23.1, R69.1, U1.25 (IO48), U3.13 (SDA), U5.12 (SDA), U7.13 (SDA), U14.14 (SDA)
SOUTH_BAT+: J11.7, J12.6, R2.1
SOUTH_IR_REC_HORI: J12.10, U10.5 (A5)
SOUTH_IR_REC_VERT: J12.12, U10.1 (A4)
SOUTH_IR_TRA_HORI: J12.11, U12.5 (A5)
SOUTH_IR_TRA_VERT: J12.13, U12.1 (A4)
SOUTH_btn_A: J12.4, U7.5 (GPB4)
SOUTH_btn_B: J12.5, U7.6 (GPB5)
VBUS: J1.A4 (VBUS), J1.A9 (VBUS), J1.B4 (VBUS), J1.B9 (VBUS), JP1.1 (A), JP2.2 (B), JP3.2 (B)
WEST_BAT+: C67.1, D30.2 (A), D31.2 (A), J11.6, R1.1, R37.1, R43.2
WEST_IR_REC_HORI: J11.10, U10.4 (A7)
WEST_IR_REC_VERT: J11.12, U10.2 (A6)
WEST_IR_TRA_HORI: J11.11, U12.4 (A7)
WEST_IR_TRA_VERT: J11.13, U12.2 (A6)
WEST_btn_A: J11.4, U7.7 (GPB6)
WEST_btn_B: J11.5, U7.8 (GPB7)
WS2812_DIN: D1.4 (DIN), U1.17 (IO9)

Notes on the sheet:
SOUTH
RESET
Servo H-bridge more LED Sensors ...
power supply switch
ensure no power delivery negociation above 5V take place if this jumper is closed...
25 RGB LEDs 4 side with 6 led IR proximity 1 Battery status
BOOT mode selection
debug header
use SX1509, MCP23017 or PCA9685 they work over I2C and can be paired to an H bridge
ACTUATOR
ESP32 WIFI MCU
can only provide 20-30 mA...
Leave floating for automatic startup
I2C mode
AUDIO SPEAKER
hold RST until 3v3 is stable
USB-C input
LED 8-13
EAST
74HC4051
DC buck, IOUT=3A
3V3, bypass the power supply switch
IR Proximity sensor
IR Remote Receiver
3V3 rail
cardinalboard SOUTH
SDO = I2C least significant bit for address
1101010b = 0x5A
Microphone
GPIO expander
daughterboard (center)
600 Ohms AC 2A 0.1 Ohm CC XRSQ1918-25mH-V-1013
backup in case the energy circuit is not working
Low cutoff = 100 Hz High cutoff = 50 KHz Gain = -10 (Inverting) add 0.5*VCC Offset
Daughterboard
0100000 = 0x20
cardinalboard EAST
Charger
not used for mode 1 datasheet say to connect to GND or VCC
ES8374

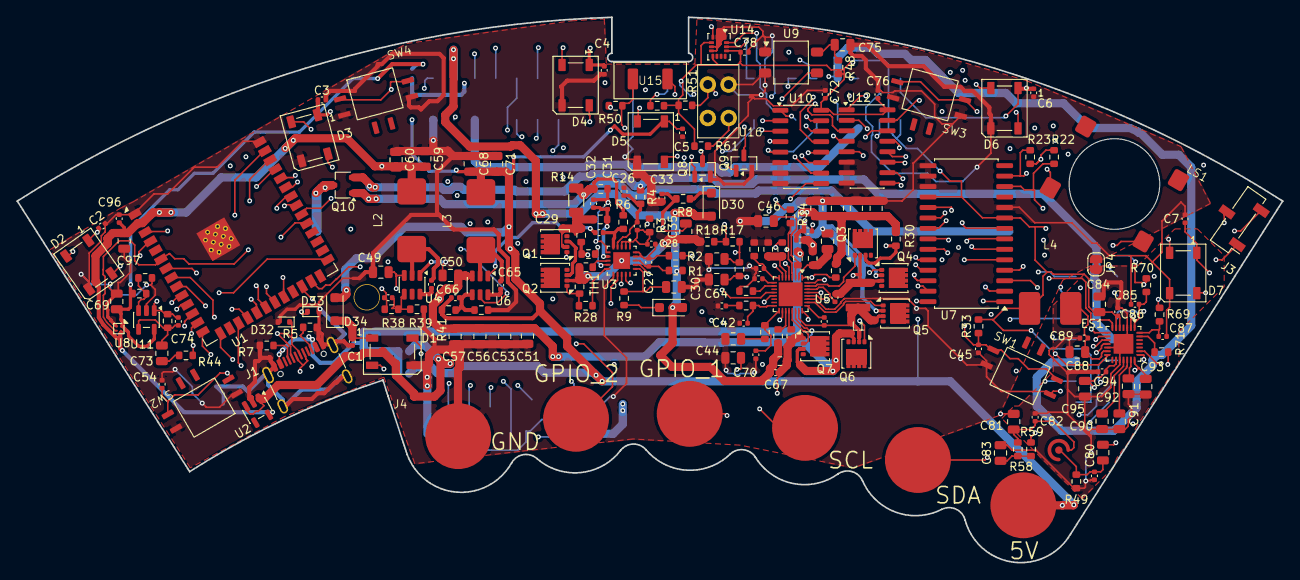
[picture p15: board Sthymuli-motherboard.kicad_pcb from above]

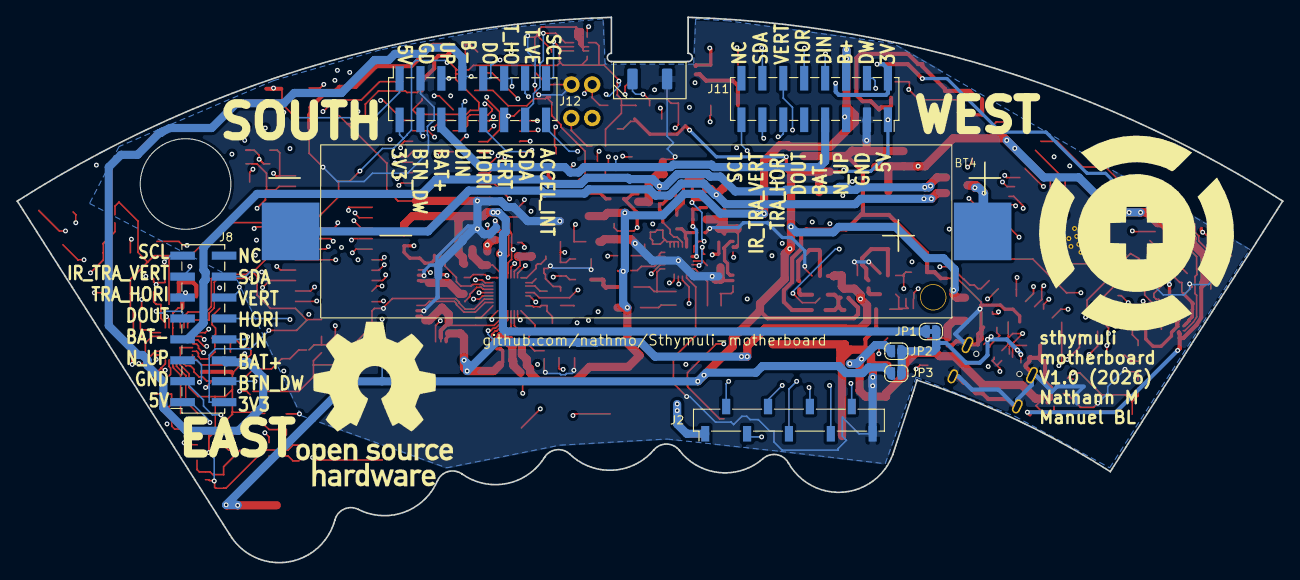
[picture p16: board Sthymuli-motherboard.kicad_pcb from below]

Board: 4 copper layers, 153.6 x 66.2 mm, 195 parts (8 on the bottom side), 164 nets.

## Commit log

2025-11-26 added empty project
    [Sthymuli-motherboard.kicad_pcb, Sthymuli-motherboard.kicad_sch]
2025-11-27 added enclosure sketch + readme + blocks of schematic
    [Sthymuli-motherboard.kicad_sch]
2025-12-19 added power switch + reflexion
    [Sthymuli-motherboard.kicad_sch]
2025-12-21 Tried to implement fast charging with USB-C PD
    likely not going to happen do to being far from trivial to implement right... I might revert to a simpler charger
    [MAX77818EWZ_T.step, Sthymuli-motherboard.kicad_sch]
2026-01-08 reimplementing the charging circuit using a known working one
    [Sthymuli-motherboard.kicad_sch]
2026-01-11 implemented new charging circuit, added USB serial
    [Sthymuli-motherboard.kicad_sch]
2026-01-11 Auto-export KiCad PDFs
2026-01-12 implemented part of audio + accel
    [Sthymuli-motherboard.kicad_sch]
2026-01-27 almost done. only the proximity sensor left to do
    [Sthymuli-motherboard.kicad_sch]
2026-02-04 schematic done
    [Sthymuli-motherboard.csv, Sthymuli-motherboard.kicad_sch]
2026-02-05 making the part list / BOM
    currently 20-30 CHF per PCB (component wise)
    [Sthymuli-motherboard.kicad_sch]
2026-02-19 upgrading ESP+ battery
    [DXF_A_MainPCB.dxf, DXF_A_MinionPCB.dxf, DXF_B_MainPCB.dxf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]
2026-02-19 upgraded to ESP32-S3, working on new power stage
    [BQ76905RGRR.step, Sthymuli-motherboard.kicad_sch]
2026-03-01 switched to LiFe, redisigned power stage
    4S lifepack
    Fastcharge
    non latching button for pwr on/off
    OTG for back powering device
    3A 5V and 3A 3v3 available for the board
    [Sthymuli-motherboard.kicad_sch]
2026-03-12 added BOM
    [Sthymuli-motherboard.csv, Sthymuli-motherboard.kicad_sch]
2026-03-12 added footprint
    [ITR-9909.stp, Sthymuli-motherboard.csv, Sthymuli-motherboard.kicad_pcb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]
2026-03-17 started layout of component
    [Sthymuli-motherboard.csv, Sthymuli-motherboard.kicad_pcb, Sthymuli-motherboard.kicad_sch]
2026-03-17 closing edgecut
    [Sthymuli-motherboard.kicad_pcb]
2026-03-25 fixed some footprint issue, advanced layout
    [Sthymuli-motherboard.kicad_pcb, Sthymuli-motherboard.kicad_sch]
2026-03-26 progress on layout
    [Sthymuli-motherboard.kicad_pcb, Sthymuli-motherboard.kicad_sch]
2026-03-31 starting from scratch the routing. autorouter was not good
    [Sthymuli-motherboard.kicad_pcb, Sthymuli-motherboard.kicad_sch]
2026-04-01 280 left to route, power mostly done
    [Sthymuli-motherboard.kicad_pcb, Sthymuli-motherboard.kicad_sch]
2026-04-02 64 left to route
    [Sthymuli-motherboard.kicad_pcb]
2026-04-02 done routing
    [Sthymuli-motherboard.kicad_pcb, Sthymuli-motherboard.kicad_sch]
2026-04-03 cleaning board
    [Sthymuli-motherboard.kicad_pcb, Sthymuli-motherboard.kicad_sch]
2026-04-04 Update KiCad repository to version 10.0
2026-04-04 done routing + cleaning PCB
    [Sthymuli-motherboard.kicad_pcb, Sthymuli-motherboard.kicad_sch]
2026-04-04 regenerated output
    [Sthymuli-motherboard-B_Cu.gbr, Sthymuli-motherboard-B_Mask.gbr, Sthymuli-motherboard-B_Paste.gbr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]
2026-04-04 added fabrication file
    [Sthymuli-motherboard.csv, Sthymuli-motherboard_BOM.csv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]
2026-04-04 Enhance README with additional details and images
    Updated README.md to improve formatting and add information about the cardinal board.
2026-04-09 slowly re routing the broken track
    fixed resistor footprint
    updated DRC checks
    improved schematic readability
    [Sthymuli-motherboard.kicad_pcb, Sthymuli-motherboard.kicad_sch]
2026-04-09 40 left
    [Sthymuli-motherboard.kicad_pcb]
2026-04-10 regenerated file + BOM
    [Sthymuli-motherboard-B_Cu.gbr, Sthymuli-motherboard-B_Mask.gbr, Sthymuli-motherboard-B_Paste.gbr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]
2026-04-10 removed kicad bck
2026-04-10 regenerated the file before placing the order
    [Sthymuli-motherboard-B_Cu.gbr, Sthymuli-motherboard-B_Mask.gbr, Sthymuli-motherboard-B_Paste.gbr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]
2026-04-10 removed all file that are obselete
    [Sthymuli-motherboard-B_Cu.gbr, Sthymuli-motherboard-B_Mask.gbr, Sthymuli-motherboard-B_Paste.gbr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]
2026-04-10 updated bom for BOTH side
    [Sthymuli-motherboard.kicad_pcb, Sthymuli-motherboard_BOM.csv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]
2026-04-10 updated header name of POS file
    [Sthymuli-motherboard-all-pos.csv]
2026-04-10 removed non populated component
    [Sthymuli-motherboard-all-pos.csv]
2026-10-16 working on power stage
2026-10-28 removed deprecated, clean power supply
